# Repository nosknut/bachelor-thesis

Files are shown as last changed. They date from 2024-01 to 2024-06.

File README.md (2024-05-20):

# Bachelor Thesis

This repository was developed as part of an Electronic Engineering Bachelor Thesis. The [report](report.pdf) serves as a design and maintainance document and contains useful information and diagrams explaining the different software mechanisms.

## Setup

### Windows (WSL)

- [WSL Setup](docs/setup/wsl/wsl/README.md)
- [Docker Setup](docs/setup/wsl/docker/README.md)

### Ubuntu

- [ROS2 Setup](https://docs.ros.org/en/humble/Installation/Ubuntu-Install-Debians.html)

### Common

After cloning the repository, run the following command to ignore changes to the workspace configs:

```bash
bash scripts/git/ignore_local_config_file_changes.bash
```

## Docs

- [Config Explanations](docs/config-explanations/README.md)
- [Docker Commands](docs/docker-commands/README.md)

## Project overview

The project contains 6 ROS2 packages:

- twig
  - The main entry point of the robot. The other packages in the project should not be used directly, but rather be included in launchfiles from this package.
- twig_description
  - Contains the URDF for the robot
- twig_servo
  - Contains the moveit_servo note that allows jogging individual joints through moveit's planning interface.
- twig_teleop
  - Contains two separate nodes that turn joy messages into useful commands for other nodes.
- twig_moveit_config
  - A moveit config package generated by the [Moveit Setup Assistant](https://moveit.picknik.ai/main/doc/examples/setup_assistant/setup_assistant_tutorial.html). It handles kinematics, path planning, collision avoidance and has an action server for requesting target positions.
- twig_hardware
  - Contains the ros2_control hardware interfaces for the robot, as well as a diagnostics node for debugging that does not use ros2_control.

## Cleaning the workspace

```bash
bash scripts/ros2/purge.bash
```

## Installing dependencies

```bash
bash scripts/ros2/install-dependencies.bash
```

## Building

```bash
bash scripts/ros2/build-packages.bash
```

## Launching

The project contains 3 different launch configurations.
- Normal Operation
  - Requires hardware
  - Based on ros2_control and MoveIt
  - Contains
    - collision, endpoint and singularity avoidance
    - Transform publishers
    - PID controllers
- Diagnostics
  - Requires hardware
  - Contains
    - A single simple hardware node that publishes all sensor data and forwards all commands directly to servos.
    - A teleop node to transform joy messages into servo speed and relay state commands
- ROS2 Development
  - Does not require hardware
  - Identical to Normal Operation
  - Replaces the hardware interfaces with Mocked Components from ros2_control

### Normal Operation

On the robot

```bash
ros2 launch twig robot_moveit.launch.py
ros2 launch twig servo_teleop.launch.py
```

On the GUI pc

```bash
ros2 launch twig joy.launch.py
ros2 launch twig foxglove.launch.py
```

and optionally on the GUI pc

```bash
ros2 launch twig rviz.launch.py
```

### Diagnostics

On the robot

```bash
ros2 launch twig diagnostics.launch.py
```

On the GUI pc

```bash
ros2 launch twig joy.launch.py
ros2 launch twig foxglove.launch.py
```

## ROS2 Development

```bash
ros2 launch twig moveit_demo.launch.py
```

Publish to /twig_joy using the foxglove Joystick node.

## Development

For development, [open the repository in the ROS2 devcontainer](https://code.visualstudio.com/docs/devcontainers/containers), and use the ROS2 task buttons in the status bar to install dependencies and build the project. While in the devcontainer, use the ROS2 Development configuration to run the project and visualize the robots physical state in RVIz. For more detailed information surrounding the development environment, refer to the [original template](https://github.com/athackst/vscode_ros2_workspace) by athackst.

In [Command Palette](https://code.visualstudio.com/docs/getstarted/userinterface#_command-palette):
```
Dev Containers: Reopen in Container
Tasks: Run Task
  ROS2: Install Dependencies
  ROS2: Build Packages
  ROS2: Run Package
```

## Citations

When citing software, docs and configuration:

```bibtex
@online{
    author = "Knut Ola Nøsen",
    title = "Subsea 3DOF Robotic Manipulator",
    url = "https://github.com/nosknut/bachelor-thesis/tree/submitted-with-report",
    urldate = "2024-05-20"
}
```

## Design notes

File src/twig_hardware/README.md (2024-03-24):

https://github.com/vortexntnu/vortex-asv/tree/master/motion/thruster_interface

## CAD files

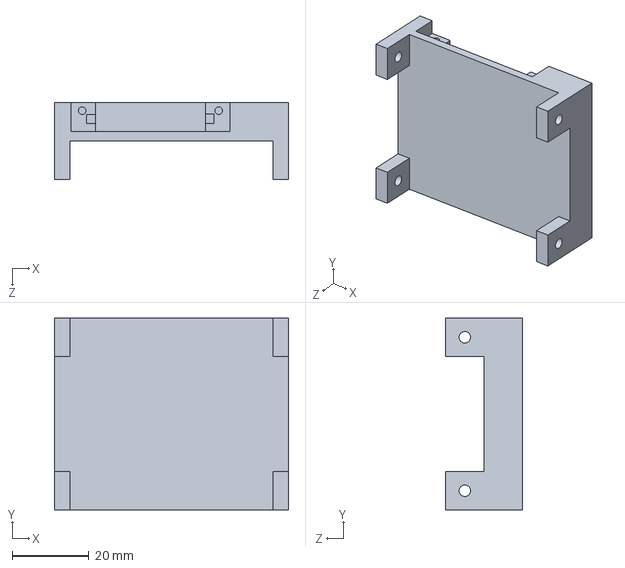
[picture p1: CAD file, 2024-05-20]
src/twig_3d_models/twig/twig_main_housing_encoder_gripper_mount_2.SLDPRT
61.0 x 50.0 x 20.0 mm

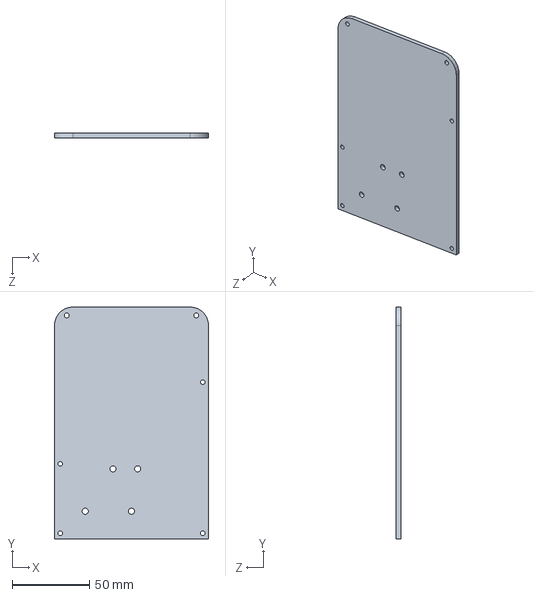
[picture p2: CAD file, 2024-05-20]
src/twig_3d_models/twig/twig_main_housing_top_lid.SLDPRT
100.0 x 150.5 x 3.00 mm

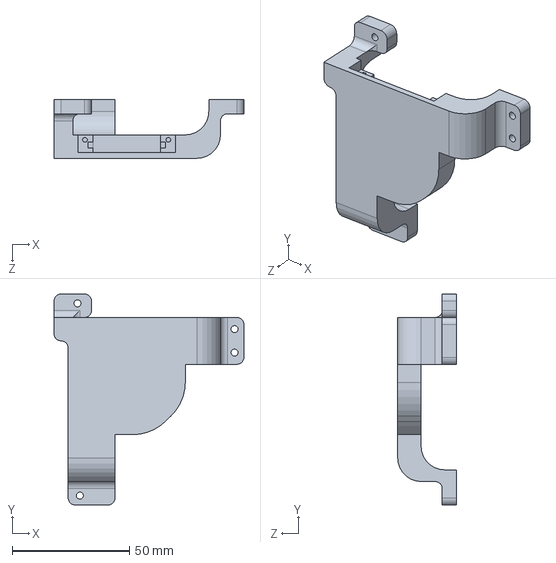
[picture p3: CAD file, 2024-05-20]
src/twig_3d_models/twig/twig_main_housing_encoder_wrist_mount_2.SLDPRT
81.0 x 90.0 x 25.0 mm

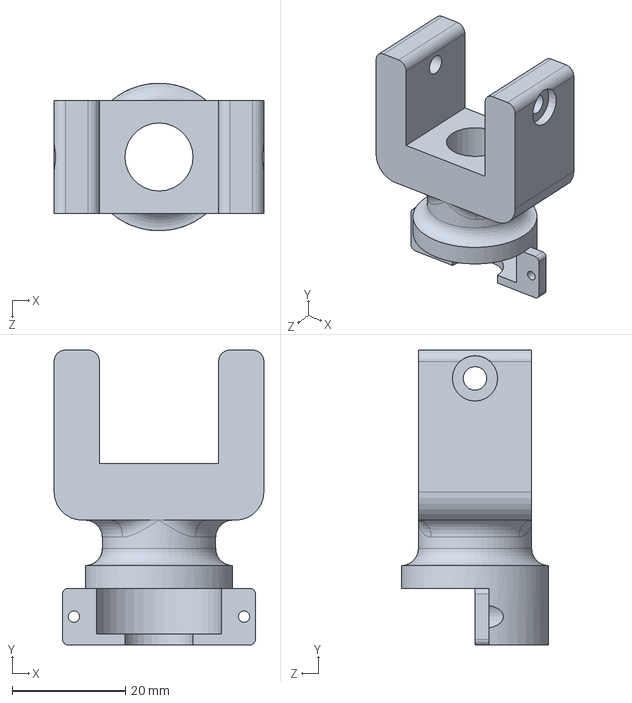
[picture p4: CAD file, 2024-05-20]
src/twig_3d_models/twig/twig_arm_clamping_movable adapter.SLDPRT
37.0 x 52.0 x 26.0 mm

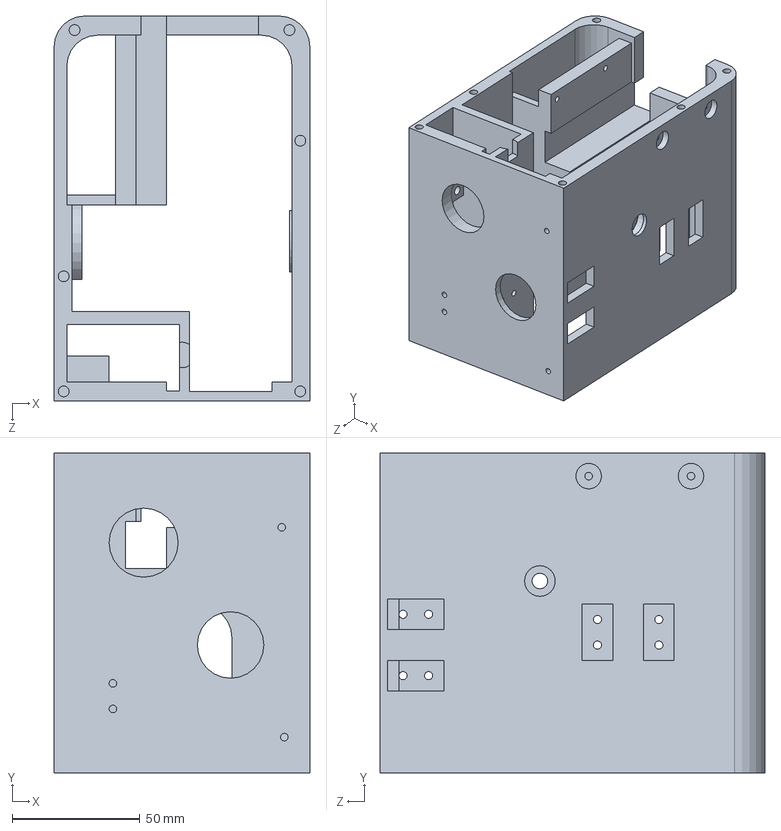
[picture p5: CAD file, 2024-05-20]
src/twig_3d_models/twig/twig_housing.SLDPRT
100.0 x 125.0 x 150.5 mm

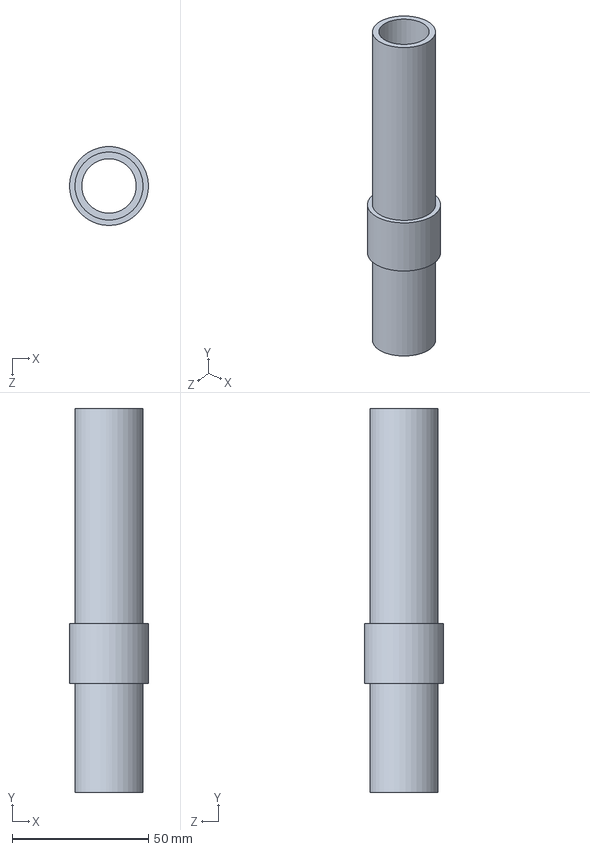
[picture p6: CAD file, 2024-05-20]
src/twig_3d_models/twig/twig_arm_innerstructure-LAPTOP-5HQE7ROM.SLDPRT
29.0 x 141.0 x 29.0 mm

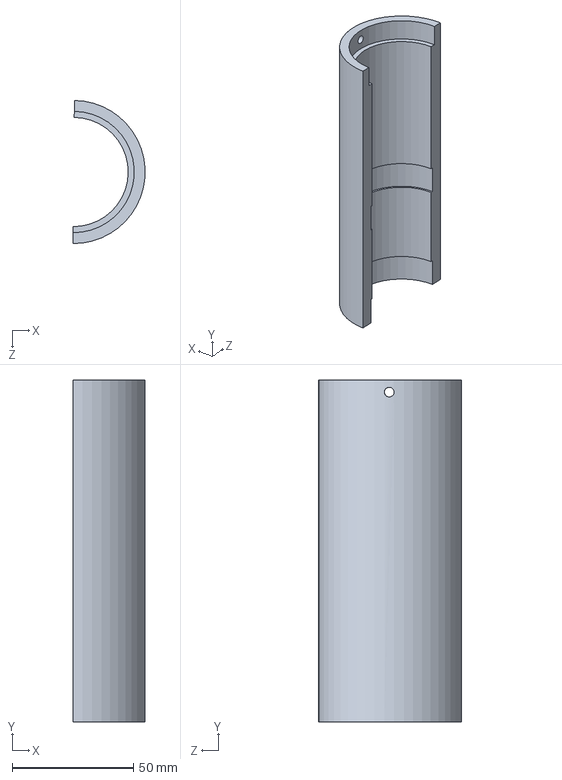
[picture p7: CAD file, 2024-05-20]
src/twig_3d_models/twig/twig_arm_outer_shell_lid-LAPTOP-5HQE7ROM.SLDPRT
29.8 x 141.0 x 59.0 mm

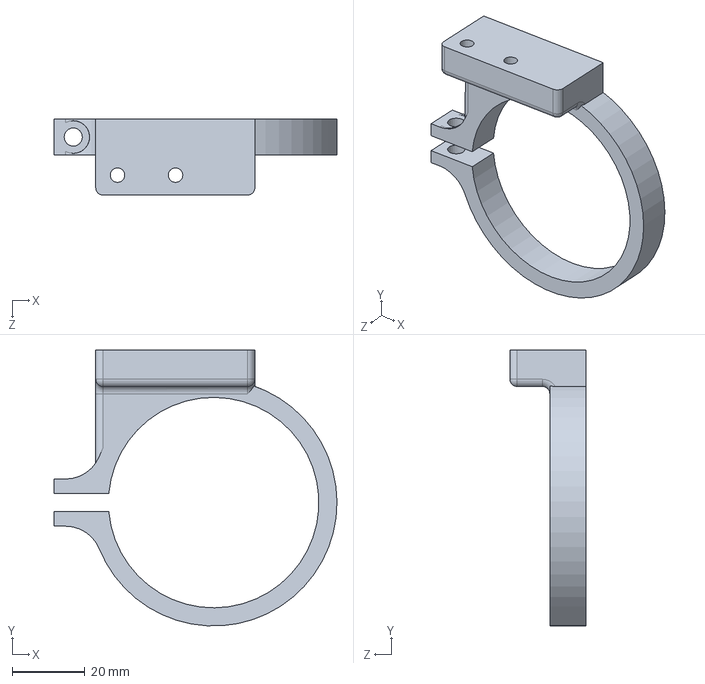
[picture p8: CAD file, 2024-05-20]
src/twig_3d_models/twig/twig_camera_adapter_2.SLDPRT
78.0 x 75.9 x 21.0 mm

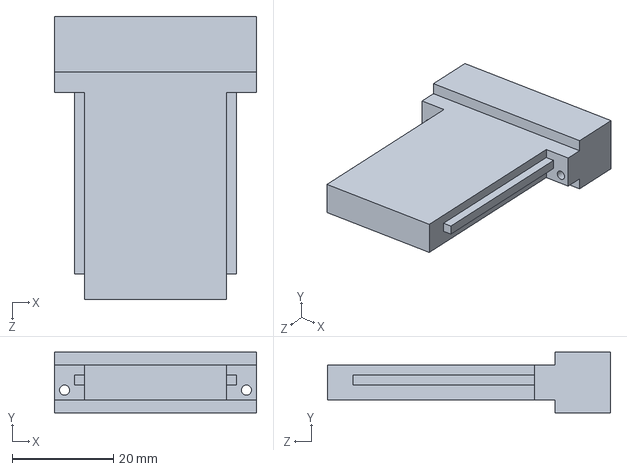
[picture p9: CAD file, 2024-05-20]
src/twig_3d_models/twig/twig_encoder_cartridge.SLDPRT
40.0 x 12.0 x 56.0 mm

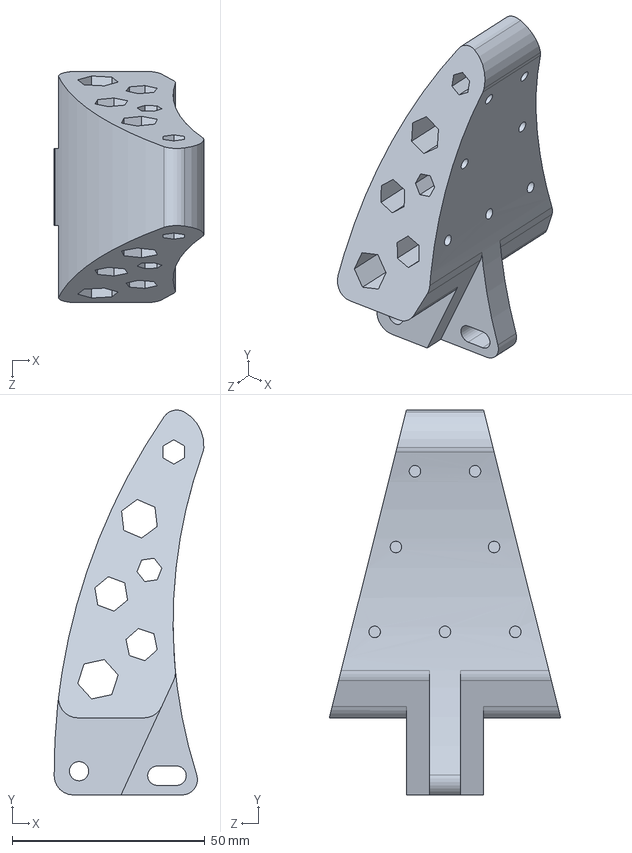
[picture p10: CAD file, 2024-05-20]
src/twig_3d_models/twig/twig_arm_clamping_claw_part_2.SLDPRT
38.8 x 99.8 x 60.0 mm

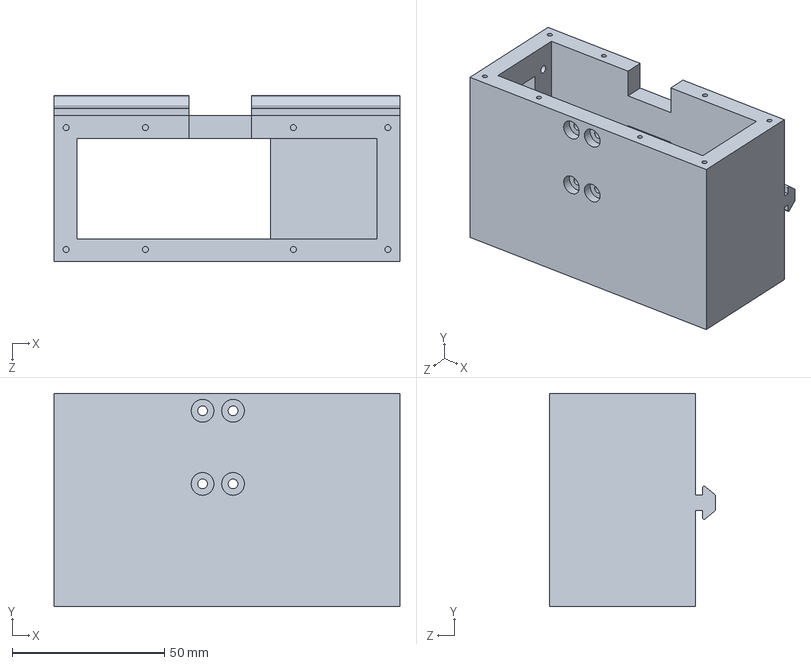
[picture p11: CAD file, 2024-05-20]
src/twig_3d_models/twig/twig_side_mounts_right_servo_housing.SLDPRT
113.6 x 70.0 x 54.6 mm

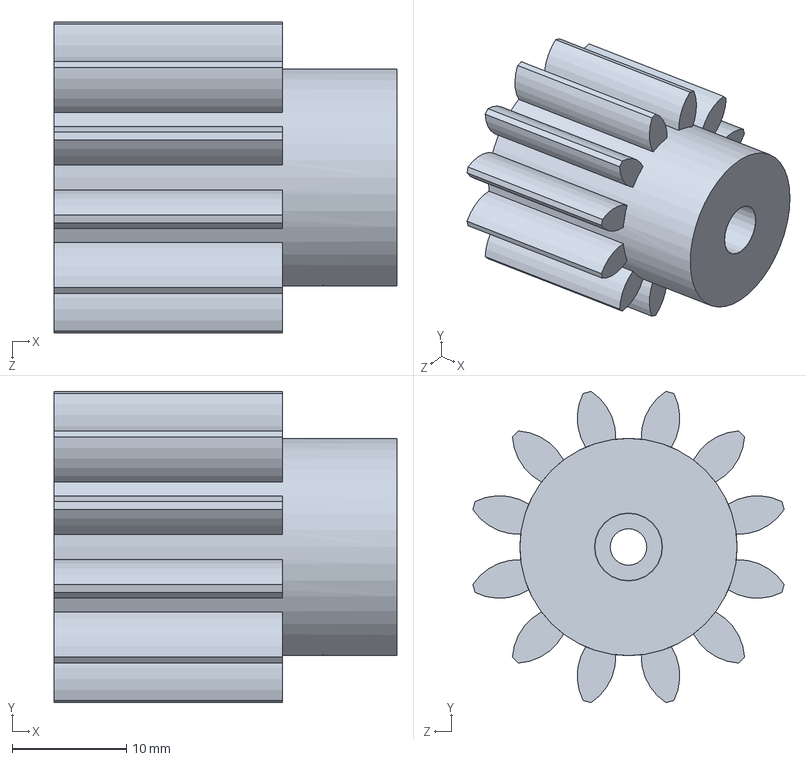
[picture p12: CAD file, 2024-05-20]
src/twig_3d_models/twig/twig_housing_gripper_pinion.SLDPRT
30.0 x 27.2 x 27.2 mm

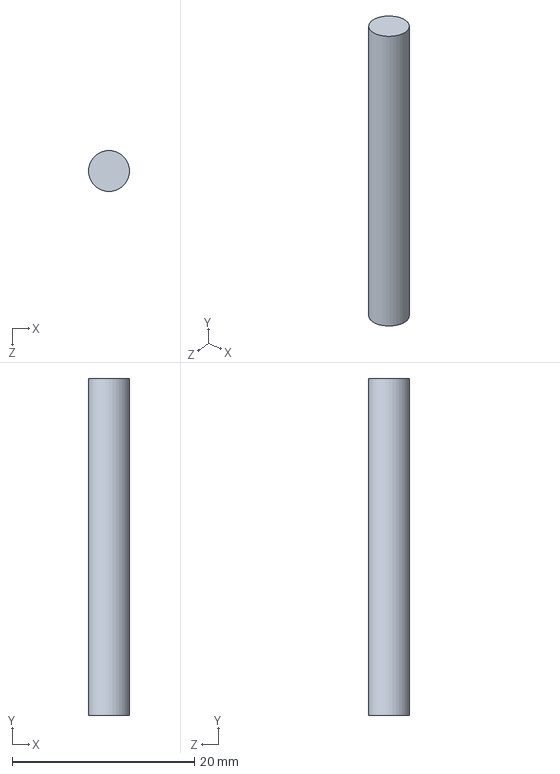
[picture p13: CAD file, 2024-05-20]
src/twig_3d_models/twig/twig_arm_clamping_pin4_movable_adapter.SLDPRT
4.50 x 37.0 x 4.50 mm

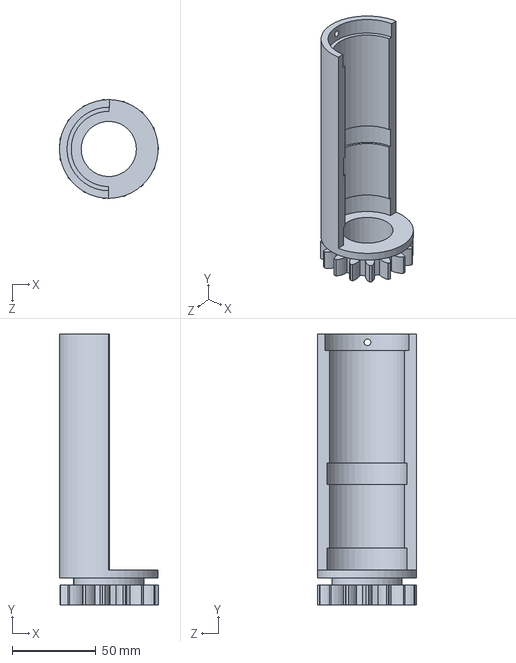
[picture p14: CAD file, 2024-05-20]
src/twig_3d_models/twig/twig_arm_outer_shell_gear.SLDPRT
59.2 x 162.0 x 59.3 mm

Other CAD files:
src/twig_3d_models/twig/twig_housing_assembly.SLDASM
src/twig_3d_models/twig/twig_arm_assembly.SLDASM
src/twig_3d_models/twig/twig_housing_gripper_rack_gear.SLDPRT
src/twig_3d_models/twig/twig_arm_innerstructure.SLDPRT
src/twig_3d_models/twig/twig_arm_47mm_bearing.SLDPRT
src/twig_3d_models/twig/twig_arm_center_shaft.SLDPRT
src/twig_3d_models/twig/twig_arm_clamping_adapter_claw.SLDPRT
src/twig_3d_models/twig/twig_arm_clamping_claw part_1.SLDPRT
src/twig_3d_models/twig/twig_arm_clamping_m6_rod.SLDPRT
src/twig_3d_models/twig/twig_arm_clamping_movable adapter_part2.SLDPRT
src/twig_3d_models/twig/twig_arm_clamping_rotating_pins.SLDPRT
src/twig_3d_models/twig/twig_arm_innerlockring.SLDPRT
src/twig_3d_models/twig/twig_arm_outer_shell_gear-LAPTOP-5HQE7ROM.SLDPRT
src/twig_3d_models/twig/twig_arm_outer_shell_lid.SLDPRT
src/twig_3d_models/twig/twig_camera_adapter_1.SLDPRT
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

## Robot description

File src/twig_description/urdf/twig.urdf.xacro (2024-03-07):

<?xml version="1.0"?>

<robot xmlns:xacro="http://www.ros.org/wiki/xacro" name="twig">

  <xacro:property name="name" value="twig" />

  <xacro:property name="base_length" value="0.08" />
  <xacro:property name="base_radius" value="0.12" />
  <xacro:property name="base_width" value="0.1" />

  <xacro:property name="shoulder_length" value="0.2" />
  <xacro:property name="shoulder_radius" value="0.05" />
  
  <xacro:property name="wrist_length" value="0.01" />
  <xacro:property name="wrist_radius" value="0.05" />

  <xacro:property name="gripper_length" value="0.05" />
  <xacro:property name="gripper_width" value="0.05" />
  <xacro:property name="gripper_height" value="0.1" />

  <xacro:property name="shoulder_limit" value="${(pi/180)*100}" />
  <xacro:property name="wrist_limit" value="${(pi/180)*360}" />
  <xacro:property name="gripper_limit" value="${(pi/180)*20}" />

  <xacro:property name="shoulder_velocity_limit" value="5.0" />
  <xacro:property name="wrist_velocity_limit" value="5.0" />
  <xacro:property name="gripper_velocity_limit" value="1.0" />

  <xacro:property name="shoulder_effort_limit" value="5.0" />
  <xacro:property name="wrist_effort_limit" value="5.0" />
  <xacro:property name="gripper_effort_limit" value="0.1" />


  <material name="blue">
    <color rgba="0 0 1 1" />
  </material>

  <material name="red">
    <color rgba="1 0 0 1" />
  </material>

  <material name="black">
    <color rgba="0 0 0 1" />
  </material>

  <material name="white">
    <color rgba="1 1 1 1" />
  </material>

  <material name="grey">
    <color rgba="0.5 0.5 0.5 1" />
  </material>

  <link name="base_link">
    <visual>
      <geometry>
        <cylinder length="1" radius="0.15" />
      </geometry>
      <material name="grey" />
      <origin rpy="0 ${pi/2} 0" />
    </visual>
    <collision>
      <geometry>
        <cylinder length="1" radius="0.15" />
      </geometry>
      <origin rpy="0 ${pi/2} 0" />
    </collision>
  </link>

  <link name="${name}_base">
    <visual>
      <geometry>
        <cylinder length="${base_width}" radius="${base_radius}" />
      </geometry>
      <material name="grey" />
      <origin rpy="0 ${pi/2} ${pi/2}" />
    </visual>
    <collision>
      <geometry>
        <cylinder length="${base_width}" radius="${base_radius}" />
      </geometry>
      <origin rpy="0 ${pi/2} ${pi/2}" />
    </collision>
  </link>

  <link name="${name}_shoulder">
    <visual>
      <geometry>
        <cylinder length="${shoulder_length}" radius="${shoulder_radius}" />
      </geometry>
      <origin xyz="0 0 ${shoulder_length/2}" />
      <material name="red" />
    </visual>
    <collision>
      <geometry>
        <cylinder length="${shoulder_length}" radius="${shoulder_radius}" />
      </geometry>
      <origin xyz="0 0 ${shoulder_length/2}" />
    </collision>
  </link>

  <link name="${name}_wrist">
    <visual>
      <geometry>
        <cylinder length="${wrist_length}" radius="${wrist_radius}" />
      </geometry>
      <origin xyz="0 0 ${wrist_length/2}" />
      <material name="white" />
    </visual>
    <collision>
      <geometry>
        <cylinder length="${wrist_length}" radius="${wrist_radius}" />
      </geometry>
      <origin xyz="0 0 ${wrist_length/2}" />
    </collision>
  </link>

  <link name="${name}_gripper">
  </link>

  <link name="${name}_left_gripper">
    <visual>
      <geometry>
        <box size="${gripper_length} ${gripper_width} ${gripper_height}" />
      </geometry>
      <origin xyz="${-gripper_length/2} 0 ${gripper_height/2}" />
      <material name="blue" />
    </visual>
    <collision>
      <geometry>
        <box size="${gripper_length} ${gripper_width} ${gripper_height}" />
      </geometry>
      <origin xyz="${-gripper_length/2} 0 ${gripper_height/2}" />
    </collision>
  </link>

  <link name="${name}_right_gripper">
    <visual>
      <geometry>
        <box size="${gripper_length} ${gripper_width} ${gripper_height}" />
      </geometry>
      <origin xyz="${gripper_length/2} 0 ${gripper_height/2}" />
      <material name="blue" />
    </visual>
    <collision>
      <geometry>
        <box size="${gripper_length} ${gripper_width} ${gripper_height}" />
      </geometry>
      <origin xyz="${gripper_length/2} 0 ${gripper_height/2}" />
    </collision>
  </link>

  <joint name="${name}_base_joint" type="fixed">
    <parent link="base_link" />
    <child link="${name}_base" />
    <origin xyz="0.5 0 0" rpy="0 ${pi/2} 0" />
  </joint>

  <joint name="${name}_shoulder_joint" type="revolute">
    <parent link="${name}_base" />
    <child link="${name}_shoulder" />
    <axis rpy="0 0 0" xyz="0 -1 0" />
    <origin xyz="0 0 ${base_length}" />
    <limit effort="${shoulder_effort_limit}" lower="${-shoulder_limit}" upper="${shoulder_limit}" velocity="${shoulder_velocity_limit}"/>
  </joint>

  <joint name="${name}_wrist_joint" type="revolute">
    <parent link="${name}_shoulder" />
    <child link="${name}_wrist" />
    <axis rpy="0 0 0" xyz="0 0 -1" />
    <origin xyz="0 0 ${shoulder_length}" />
    <limit effort="${wrist_effort_limit}" lower="${-wrist_limit}" upper="${wrist_limit}" velocity="${wrist_velocity_limit}"/>
  </joint>

  <joint name="${name}_gripper_joint" type="fixed">
    <parent link="${name}_wrist" />
    <child link="${name}_gripper" />
    <origin xyz="0 0 ${gripper_height}" />
  </joint>

  <joint name="${name}_left_finger_joint" type="revolute">
    <parent link="${name}_wrist" />
    <child link="${name}_left_gripper" />
    <axis rpy="0 0 0" xyz="0 -1 0" />
    <limit effort="${gripper_effort_limit}" lower="0" upper="${gripper_limit}" velocity="${gripper_velocity_limit}"/>
  </joint>

  <joint name="${name}_right_finger_joint" type="revolute">
    <parent link="${name}_wrist" />
    <child link="${name}_right_gripper" />
    <axis rpy="0 0 0" xyz="0 1 0" />
    <limit effort="${gripper_effort_limit}" lower="0" upper="${gripper_limit}" velocity="${gripper_velocity_limit}"/>
    <mimic joint="twig_left_finger_joint" />
  </joint>
</robot>

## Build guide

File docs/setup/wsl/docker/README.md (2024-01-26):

[<-- Back](/README.md)

# Docker

Docker is a service that allows you to run applications in containers without installing the programs on your actual machine. This allows for a standardized environment for running applications, and makes it easier to share code with others. It also takes a lot of debugging off your hands when working across different computers and team members.

## Install Docker

Follow the instructions on [this](https://docs.docker.com/desktop/install/windows-install/) website to install docker.

## Configure Docker in WSL

Follow the instructions on [this](https://docs.docker.com/desktop/wsl/) website to make docker commands available in the WSL terminal.

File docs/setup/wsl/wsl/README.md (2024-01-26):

[<-- Back](/README.md)

# WSL

The following instructions are for installing and using windows subsystem for linux (WSL), which allows you to run docker desktop and linux GUI applications directly in windows.

## Install WSL

- Follow the instructions in [this](https://youtu.be/AMlaEFaKG88?si=Uk1TH-ulXn2jgdA9) video or [this](https://docs.microsoft.com/en-us/windows/wsl/install-win10) website to install WSL.
- Make sure WSL2 is the default version
```bash
wsl --set-default-version 2
```
- [Install Ubuntu WSL](https://apps.microsoft.com/detail/9PDXGNCFSCZV?hl=en-us&gl=US) from the Microsoft Store.
- Run the setup by launching the Ubuntu app from the start menu
- [Configure WSL GUI Support](https://learn.microsoft.com/en-us/windows/wsl/tutorials/gui-apps) by running the following commands in powershell
```bash
wsl --update
```

## Launch wsl terminal from VSCode

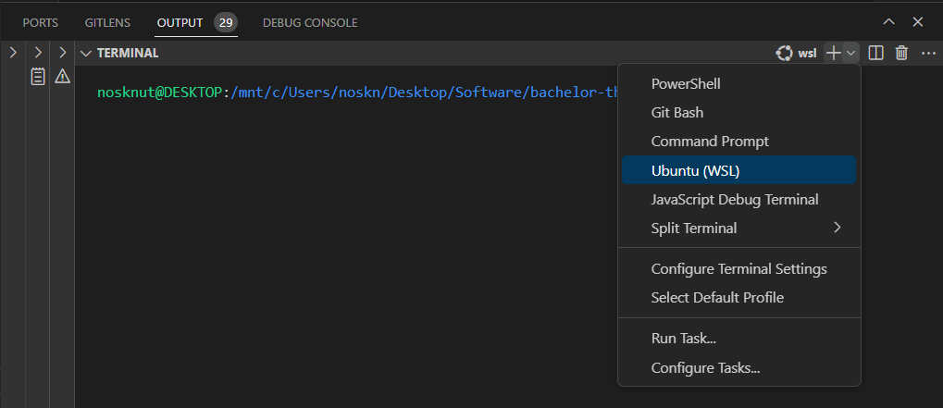
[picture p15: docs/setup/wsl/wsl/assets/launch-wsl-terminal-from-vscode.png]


## Create symlink to project in WSL home directory

It is practical to create a shortcut the project folder in the WSL home directory. This way, you can easily access the project folder from any GUI application running in WSL.

```bash
ln -s /mnt/c/Users/username/path/to/<project-name> ~/<project-name>
```

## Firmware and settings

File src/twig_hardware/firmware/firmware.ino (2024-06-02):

// How to flash the firmware to Raspberry Pi Pico from Arduino IDE:
// https://randomnerdtutorials.com/programming-raspberry-pi-pico-w-arduino-ide/#Raspberry-Pi-Pico-Boards-Manager
// Additional URL:
// https://github.com/earlephilhower/arduino-pico/releases/download/global/package_rp2040_index.json
// Board manager:
// Raspberry Pi Pico/RP2040 by Earle F. Philhower, III Version 3.8.0 INSTALLED
// Serial port not showing up:
// https://forum.arduino.cc/t/raspberry-pi-pico-does-not-show-its-port-in-ide/850432/10

#include "FirmwareConfig.h"

#include <Wire.h>
#include <Servo.h>
#include "hardware/watchdog.h"
#include "TwigState.h"
#include "TwigCommand.h"
#include "TwigHardwareConfig.h"
#include "FusedServo.h"
#include "I2cMultiplexer.h"

// #define DEBUG_ENCODERS
#include "Encoder.h"

I2cMultiplexer i2cMultiplexer = I2cMultiplexer(Wire1, MULTIPLEXER_ADDRESS);
Encoder shoulderEncoder = Encoder(i2cMultiplexer, SHOULDER_ENCODER_CHANNEL, INITIAL_MIN_ENCODER_MAGNITUDE, "Shoulder");
Encoder wristEncoder = Encoder(i2cMultiplexer, WRIST_ENCODER_CHANNEL, INITIAL_MIN_ENCODER_MAGNITUDE, "Wrist");
Encoder gripperEncoder = Encoder(i2cMultiplexer, GRIPPER_ENCODER_CHANNEL, INITIAL_MIN_ENCODER_MAGNITUDE, "Gripper");

FusedServo shoulderServo(SHOULDER_SERVO_PIN, SHOULDER_SERVO_RELAY_PIN);
FusedServo wristServo(WRIST_SERVO_PIN, WRIST_SERVO_RELAY_PIN);
FusedServo gripperServo(GRIPPER_SERVO_PIN, GRIPPER_SERVO_RELAY_PIN);

TwigCommand twigCommand;
TwigState twigState;

unsigned long connectionTimeout = INITIAL_CONNECTION_TIMEOUT;
unsigned long connectionTimer = 0;
unsigned long logTimer = 0;

unsigned long sent = 0;
unsigned long received = 0;

void resetCommand()
{
  twigCommand.sessionId = twigState.sessionId;
  twigCommand.shoulder = 0;
  twigCommand.wrist = 0;
  twigCommand.gripper = 0;
  twigCommand.shoulderServoPowered = false;
  twigCommand.wristServoPowered = false;
  twigCommand.gripperServoPowered = false;
}

bool verify_session_id()
{
  return twigCommand.sessionId == twigState.sessionId;
}

void updateHardwareConfig() {
  TwigHardwareConfig &config = twigCommand.config;

  connectionTimeout = config.connectionTimeout;

  shoulderEncoder.minMagnitude = config.encoderMinMagnitude;
  wristEncoder.minMagnitude = config.encoderMinMagnitude;
  gripperEncoder.minMagnitude = config.encoderMinMagnitude;

  shoulderServo.fuse.maxCurrent = config.maxShoulderCurrent;
  wristServo.fuse.maxCurrent = config.maxWristCurrent;
  gripperServo.fuse.maxCurrent = config.maxGripperCurrent;

  shoulderServo.fuse.maxCurrentDuration = config.maxCurrentDuration;
  wristServo.fuse.maxCurrentDuration = config.maxCurrentDuration;
  gripperServo.fuse.maxCurrentDuration = config.maxCurrentDuration;

  shoulderServo.fuse.maxCurrentCooldownDuration = config.maxCurrentCooldownDuration;
  wristServo.fuse.maxCurrentCooldownDuration = config.maxCurrentCooldownDuration;
  gripperServo.fuse.maxCurrentCooldownDuration = config.maxCurrentCooldownDuration;
}

void writeCommand()
{
  if (!verify_session_id()) return;
  shoulderServo.update(twigState.shoulderCurrent, twigCommand.shoulderServoPowered, twigCommand.shoulder);
  wristServo.update(twigState.wristCurrent, twigCommand.wristServoPowered, twigCommand.wrist);
  gripperServo.update(twigState.gripperCurrent, twigCommand.gripperServoPowered, twigCommand.gripper);
}

void onCommand(int length)
{
  TwigCommand payload;
  Wire.readBytes((uint8_t *)&payload, length);
  if (payload.integrityCheck != 85) {
    Serial.println("Command integrity check failed");
    return;
  }
  twigCommand = payload;
  updateHardwareConfig();
  if (verify_session_id()) connectionTimer = millis();
  received++;
}

void readState()
{
  twigState.wristCurrent = analogRead(WRIST_CURRENT_PIN);
  twigState.gripperCurrent = analogRead(GRIPPER_CURRENT_PIN);
  twigState.shoulderCurrent = analogRead(SHOULDER_CURRENT_PIN);

  twigState.wristPosition = wristEncoder.values.angle;
  twigState.wristVelocity = wristEncoder.values.velocity;
  twigState.wristEncoderMagnitude = wristEncoder.values.magnitude;

  twigState.shoulderPosition = shoulderEncoder.values.angle;
  twigState.shoulderVelocity = shoulderEncoder.values.velocity;
  twigState.shoulderEncoderMagnitude = shoulderEncoder.values.magnitude;

  twigState.gripperPosition = gripperEncoder.values.angle;
  twigState.gripperVelocity = gripperEncoder.values.velocity;
  twigState.gripperEncoderMagnitude = gripperEncoder.values.magnitude;

  twigState.wristServoPowered = wristServo.relayState;
  twigState.shoulderServoPowered = shoulderServo.relayState;
  twigState.gripperServoPowered = gripperServo.relayState;
}

void onStateRequest()
{
  Wire.write((uint8_t *)&twigState, sizeof(TwigState));
  if (verify_session_id()) connectionTimer = millis();
  sent++;
}

void setupOutputs()
{
  shoulderServo.begin();
  wristServo.begin();
  gripperServo.begin();
}

String leadingSpaces(String val, int length)
{
  int valLen = val.length();
  String out = "";
  for (int i = 0; i < length - valLen; i++)
  {
    out += " ";
  }
  out += val;
  return out;
}

void printLog()
{
  Serial.print("Sending at: ");
  Serial.print(sent * 10);
  Serial.print("Hz, Receiving at: ");
  Serial.print(received * 10);
  Serial.print("Hz, ");
  Serial.print(leadingSpaces(String(twigCommand.shoulder), 7));
  Serial.print(", ");
  Serial.print(leadingSpaces(String(twigCommand.wrist), 7));
  Serial.print(", ");
  Serial.print(leadingSpaces(String(twigCommand.gripper), 7));
  Serial.print(", ");
  Serial.print(leadingSpaces(String(twigState.shoulderEncoderMagnitude), 7));
  Serial.print(", ");
  Serial.print(leadingSpaces(String(twigState.wristEncoderMagnitude), 7));
  Serial.print(", ");
  Serial.print(leadingSpaces(String(twigState.gripperEncoderMagnitude), 7));
  Serial.print(", ");
  Serial.print(twigCommand.shoulderServoPowered);
  Serial.print(", ");
  Serial.print(twigCommand.wristServoPowered);
  Serial.print(", ");
  Serial.println(twigCommand.gripperServoPowered);
}

void updateLog()
{
  if ((millis() - logTimer) >= 100)
  {
    printLog();
    sent = 0;
    received = 0;
    logTimer = millis();
  }
}

void updateConnectionTimer()
{
  if ((millis() - connectionTimer) > connectionTimeout)
  {
    resetCommand();
    Serial.println("Connection timeout");
  }
}

void setup()
{
  // Used to detect that the microcontroller rebooted
  randomSeed(analogRead(SESSION_ID_RANDOM_SEED_PIN));
  twigState.sessionId = random(1, 10000);

  setupOutputs();
  resetCommand();

  Serial.begin(SERIAL_BAUD_RATE);

  Serial.println("Starting ...");

  // https://github.com/raspberrypi/pico-examples/blob/master/watchdog/hello_watchdog/hello_watchdog.c
  // Enable the watchdog, requiring the watchdog to be updated every 100ms or the chip will reboot
  // second arg is pause on debug which means the watchdog will pause when stepping through code
  watchdog_enable(1000, 1);

  Wire.setSCL(RASPBERRY_PI_SCL_PIN);
  Wire.setSDA(RASPBERRY_PI_SDA_PIN);
  
  Wire.begin(I2C_ADDRESS);
  Wire.onReceive(onCommand);
  Wire.onRequest(onStateRequest);

}

void loop()
{
    readState();
    updateLog();
    updateConnectionTimer();
    writeCommand();
    watchdog_update();
}

// The encoders might crash if they get destroyed, which can freeze the firmware.
// To allow normal operations without the encoders, they are exclusively read and updated
// in a separate core.
void setup1()
{
  Wire1.setSCL(MULTIPLEXER_SCL_PIN);
  Wire1.setSDA(MULTIPLEXER_SDA_PIN);
  Wire1.setClock(MULTIPLEXER_FREQUENCY);
  Wire1.setTimeout(MULTIPLEXER_TIMEOUT);
  Wire1.begin();
}

// The encoders might crash if they get destroyed, which can freeze the firmware.
// To allow normal operations without the encoders, they are exclusively read and updated
// in a separate core.
void loop1()
{
  wristEncoder.update();
  shoulderEncoder.update();
  // TODO: Fix the gripper encoder and re-enable it in firmware
  // gripperEncoder.update();
}

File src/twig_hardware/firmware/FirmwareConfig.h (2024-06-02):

#ifndef FIRMWARE_CONFIG_h
#define FIRMWARE_CONFIG_h

const int8_t I2C_ADDRESS = 30;
const unsigned long SERIAL_BAUD_RATE = 115200;

const int SERVO_STATIONARY_SIGNAL = 1500;

const int INITIAL_MIN_ENCODER_MAGNITUDE = 10;

const int POSITION_LOWPASS_FILTER_ORDER = 2;
const float POSITION_LOWPASS_FILTER_CUTOFF = 2.0;

// To protect the system in the event of a connection loss,
// the system will stop moving if it does not detect activity
// within the specified number of milliseconds.
const unsigned long INITIAL_CONNECTION_TIMEOUT = 200;

const int8_t RASPBERRY_PI_SDA_PIN = 20;
const int8_t RASPBERRY_PI_SCL_PIN = 21;

// https://www.elfadistrelec.no/no/i2c-multiplexer-adafruit-2717/p/30091194
const uint32_t MULTIPLEXER_FREQUENCY = 100e3;
const uint32_t MULTIPLEXER_TIMEOUT = 500;
const int8_t MULTIPLEXER_ADDRESS = 0x70;
const int8_t MULTIPLEXER_SCL_PIN = 19;
const int8_t MULTIPLEXER_SDA_PIN = 18;

const int8_t SHOULDER_ENCODER_CHANNEL = 3;
const int8_t WRIST_ENCODER_CHANNEL = 2;
const int8_t GRIPPER_ENCODER_CHANNEL = 4;

const int8_t SHOULDER_CURRENT_PIN = A0;
const int8_t WRIST_CURRENT_PIN = A1;
const int8_t GRIPPER_CURRENT_PIN = A2;

const int8_t SESSION_ID_RANDOM_SEED_PIN = A2;

const int8_t SHOULDER_SERVO_PIN = 3;
const int8_t WRIST_SERVO_PIN = 12;
const int8_t GRIPPER_SERVO_PIN = 8;

const int8_t SHOULDER_SERVO_RELAY_PIN = 9;
const int8_t WRIST_SERVO_RELAY_PIN = 11;
const int8_t GRIPPER_SERVO_RELAY_PIN = 10;

#endif

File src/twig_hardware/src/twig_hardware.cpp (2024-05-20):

// https://github.com/ros-controls/ros2_control_demos/blob/humble/example_12/hardware/rrbot.cpp

// Copyright 2023 ros2_control Development Team
//
// Licensed under the Apache License, Version 2.0 (the "License");
// you may not use this file except in compliance with the License.
// You may obtain a copy of the License at
//
//     http://www.apache.org/licenses/LICENSE-2.0
//
// Unless required by applicable law or agreed to in writing, software
// distributed under the License is distributed on an "AS IS" BASIS,
// WITHOUT WARRANTIES OR CONDITIONS OF ANY KIND, either express or implied.
// See the License for the specific language governing permissions and
// limitations under the License.

#include "twig_hardware/twig_hardware.hpp"

#include <chrono>
#include <cmath>
#include <limits>
#include <memory>
#include <vector>

#include "hardware_interface/types/hardware_interface_type_values.hpp"
#include "rclcpp/rclcpp.hpp"

namespace twig_hardware
{
hardware_interface::CallbackReturn TwigHardware::on_init(
  const hardware_interface::HardwareInfo & info)
{
  if (
    hardware_interface::SystemInterface::on_init(info) !=
    hardware_interface::CallbackReturn::SUCCESS)
  {
    return hardware_interface::CallbackReturn::ERROR;
  }

  hw_commands_.resize(info_.joints.size() * 1, std::numeric_limits<double>::quiet_NaN());
  hw_states_.resize(info_.joints.size() * 3, std::numeric_limits<double>::quiet_NaN());

  for (const hardware_interface::ComponentInfo & joint : info_.joints) {
    // TwigHardware has exactly 1 command and 3 state interfaces on each joint

    // Validate command interface configs

    if (joint.command_interfaces.size() != 1) {
      RCLCPP_FATAL(
        rclcpp::get_logger("TwigHardware"),
        "Joint '%s' has %zu command interfaces found. 1 expected.", joint.name.c_str(),
        joint.command_interfaces.size());
      return hardware_interface::CallbackReturn::ERROR;
    }

    // Validate command interface 1 config

    if (joint.command_interfaces[0].name != hardware_interface::HW_IF_VELOCITY) {
      RCLCPP_FATAL(
        rclcpp::get_logger("TwigHardware"),
        "Joint '%s' have %s command interfaces found. '%s' expected.", joint.name.c_str(),
        joint.command_interfaces[0].name.c_str(), hardware_interface::HW_IF_VELOCITY);
      return hardware_interface::CallbackReturn::ERROR;
    }

    // Validate state interface configs

    if (joint.state_interfaces.size() != 3) {
      RCLCPP_FATAL(
        rclcpp::get_logger("TwigHardware"),
        "Joint '%s' has %zu state interface. 3 expected.", joint.name.c_str(),
        joint.state_interfaces.size());
      return hardware_interface::CallbackReturn::ERROR;
    }

    // Validate state interface 1 config

    if (joint.state_interfaces[0].name != hardware_interface::HW_IF_POSITION) {
      RCLCPP_FATAL(
        rclcpp::get_logger("TwigHardware"),
        "Joint '%s' have %s state interface. '%s' expected.", joint.name.c_str(),
        joint.state_interfaces[0].name.c_str(), hardware_interface::HW_IF_POSITION);
      return hardware_interface::CallbackReturn::ERROR;
    }

    // Validate state interface 2 config

    if (joint.state_interfaces[1].name != hardware_interface::HW_IF_VELOCITY) {
      RCLCPP_FATAL(
        rclcpp::get_logger("TwigHardware"),
        "Joint '%s' have %s state interface. '%s' expected.", joint.name.c_str(),
        joint.state_interfaces[1].name.c_str(), hardware_interface::HW_IF_VELOCITY);
      return hardware_interface::CallbackReturn::ERROR;
    }

    // Validate state interface 3 config

    if (joint.state_interfaces[2].name != hardware_interface::HW_IF_EFFORT) {
      RCLCPP_FATAL(
        rclcpp::get_logger("TwigHardware"),
        "Joint '%s' have %s state interface. '%s' expected.", joint.name.c_str(),
        joint.state_interfaces[2].name.c_str(), hardware_interface::HW_IF_EFFORT);
      return hardware_interface::CallbackReturn::ERROR;
    }
  }

  
  // Configure the pull and push rates
  // https://control.ros.org/master/doc/ros2_control/hardware_interface/doc/different_update_rates_userdoc.html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
  pull_rate_ = stod(info_.hardware_parameters["pull_rate"]);
  push_rate_ = stod(info_.hardware_parameters["push_rate"]);


  return hardware_interface::CallbackReturn::SUCCESS;
}

hardware_interface::CallbackReturn TwigHardware::on_configure(
  const rclcpp_lifecycle::State & /*previous_state*/)
{
  for (uint i = 0; i < hw_states_.size(); i++) {
    hw_states_[i] = 0;
  }

  for (uint i = 0; i < hw_commands_.size(); i++) {
    hw_commands_[i] = 0;
  }

  // Docs for hardware params:
  // https://control.ros.org/master/doc/ros2_control/hardware_interface/doc/different_update_rates_userdoc.html
  
  // Load all twig driver hardware configurations from hardware params
  TwigHardwareConfig c;
  c.connectionTimeout = stoi(info_.hardware_parameters["hardware_config.connection_timeout"]);
  
  c.maxShoulderCurrent = twig.current_to_raw_psm(stod(info_.hardware_parameters["hardware_config.max_current"]));
  c.maxWristCurrent = twig.current_to_raw_psm(stod(info_.hardware_parameters["hardware_config.max_current"]));
  c.maxGripperCurrent = twig.current_to_raw_acs(stod(info_.hardware_parameters["hardware_config.max_current"]));
  c.maxCurrentDuration = stoi(info_.hardware_parameters["hardware_config.max_current_duration"]);
  c.maxCurrentCooldownDuration = stoi(info_.hardware_parameters["hardware_config.max_current_cooldown_duration"]);
  c.encoderMinMagnitude = stoi(info_.hardware_parameters["hardware_config.encoder_min_magnitude"]);
  twig.set_hardware_config(c);

  // Load all twig driver joint configurations from hardware params
  twig.jointConfig.shoulderLimits.min = stod(info_.hardware_parameters["joint_config.shoulder.limits.min"]);
  twig.jointConfig.shoulderLimits.max = stod(info_.hardware_parameters["joint_config.shoulder.limits.max"]);

  twig.jointConfig.gripperLimits.min = stod(info_.hardware_parameters["joint_config.gripper.limits.min"]);
  twig.jointConfig.gripperLimits.max = stod(info_.hardware_parameters["joint_config.gripper.limits.max"]);

  twig.jointConfig.shoulderOffset = stod(info_.hardware_parameters["joint_config.shoulder.offset"]);
  twig.jointConfig.wristOffset = stod(info_.hardware_parameters["joint_config.wrist.offset"]);
  twig.jointConfig.gripperOffset = stod(info_.hardware_parameters["joint_config.gripper.offset"]);

  // Push the configurations to hardware
  if (twig.write_command()) {
    RCLCPP_INFO(rclcpp::get_logger("TwigHardware"), "Successfully configured!");
    return hardware_interface::CallbackReturn::SUCCESS;
  }

  RCLCPP_ERROR(rclcpp::get_logger("TwigHardware"), "Failed to configure hardware!");
  return hardware_interface::CallbackReturn::ERROR;
}
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

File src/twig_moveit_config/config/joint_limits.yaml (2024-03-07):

# joint_limits.yaml allows the dynamics properties specified in the URDF to be overwritten or augmented as needed

# For beginners, we downscale velocity and acceleration limits.
# You can always specify higher scaling factors (<= 1.0) in your motion requests.  # Increase the values below to 1.0 to always move at maximum speed.
default_velocity_scaling_factor: 0.1
default_acceleration_scaling_factor: 0.1

# Specific joint properties can be changed with the keys [max_position, min_position, max_velocity, max_acceleration]
# Joint limits can be turned off with [has_velocity_limits, has_acceleration_limits]
joint_limits:
  twig_left_finger_joint:
    has_velocity_limits: true
    max_velocity: 1.0
    has_acceleration_limits: false
    max_acceleration: 0.0
  twig_right_finger_joint:
    has_velocity_limits: true
    max_velocity: 1.0
    has_acceleration_limits: false
    max_acceleration: 0.0
  twig_shoulder_joint:
    has_velocity_limits: true
    max_velocity: 5.0
    has_acceleration_limits: false
    max_acceleration: 0.0
  twig_wrist_joint:
    has_velocity_limits: true
    max_velocity: 5.0
    has_acceleration_limits: false
    max_acceleration: 0.0

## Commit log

2024-01-26 Line endings
    [main.sdf]
2024-02-07 Adds urdf for manipulator
    [manipulator.urdf, manipulator.urdf.xacro]
2024-02-08 Adds panda_movit_config from moveit2 demo
    [joint_limits.yaml, panda.ros2_control.xacro, panda.urdf.xacro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]
2024-02-09 Switches to single ros2 container
2024-02-10 Removes unused gazebo files
    [main.sdf, model.sdf]
2024-02-16 Adds vscode task buttons
2024-02-27 Adds more task buttons
2024-03-01 Half-functioning teleopt
    [controller_mappings.yaml]
2024-03-07 Adds twig_description package
    [twig.urdf.xacro]
2024-03-07 Adds twig_moveit_config from MoveitSetupAssistant
    [joint_limits.yaml, ros2_controllers.yaml, twig.ros2_control.xacro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]
2024-03-07 Updates auv_manipulator urdf file
    [manipulator.urdf.xacro]
2024-03-07 Updates twig gripper velocity limits
    [joint_limits.yaml, manipulator.urdf.xacro, twig.urdf.xacro]
2024-03-07 Reverses direction or twig shoulder and wrist axis
    [twig.urdf.xacro]
2024-03-07 Removes the hand_controller to make the gripper servoable
    [ros2_controllers.yaml]
2024-03-07 Adds copy of twig_teleop renamed as panda_teleop
    [controller_mappings.yaml]
2024-03-08 Removes unused packages
    [controller_mappings.yaml, joint_limits.yaml, manipulator.urdf.xacro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]
2024-03-09 Fixes twig_teleop crashing due to empty joy message
    [joystick_teleop.config.yaml, joystick_teleop.cpp]
2024-03-14 Updates firmware i2c address
2024-03-14 Adds servo relay code to firmware
2024-03-14 Increases size of current and voltage sensor variables
2024-03-24 Adds twig_hardware
    [twig_hardware.ros2_control.xacro]
2024-03-24 Adds arduino.json config
2024-03-24 Fixes incorrect datatype for firmware baudrate
    [firmware.ino]
2024-03-24 Fixes invalid implementation syntax
    [twig_lib.cpp]
2024-03-24 Adds temporary velocity commands
2024-03-24 Changes firmware to send correct stop signal to servos
    [firmware.ino, twig_lib.cpp]
2024-03-24 Moves velocity calculation to firmware
2024-03-24 Fixes typos in direct teleop node
    [joystick_direct_teleop.cpp]
2024-03-24 Adds astop message after arm button gets released
2024-03-24 Add custom velocity tracking to firmware
2024-03-24 Use state class for i2c receive size
2024-03-24 Adds watchdog timer to firmware
2024-03-28 Removes periodic velocity computation
2024-04-20 Inverts servo relay logic
    [firmware.ino]
2024-04-20 Adds encoder magnitude publishers
2024-04-20 Simplifies teleop button configs
2024-05-04 Fixes typo in joystick_teleop
    [joystick_teleop.cpp]
2024-05-15 Adds joint limits and offsets
2024-05-15 Adds sesstions to detect hardware and driver reboots
    [TwigState.h, firmware.ino, joystick_direct_teleop.cpp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]
2024-05-15 Adds fuse
2024-05-15 Adds current unit conversion for max current params
2024-05-15 Adds driver reboot push check
    [twig_hardware_node.cpp, twig_lib.cpp]
2024-05-15 Adds improved driver sync logic
2024-05-15 Removes unused timer
2024-05-15 Adds separate encoder thread
2024-05-15 Adds separate main thread
2024-05-15 Gives main thread higher priority
2024-05-15 Adds improved lowpass filter to firmware
2024-05-15 Makes the thread run methods public for easy debugging
2024-05-15 Updates Thread.h to use static task function
2024-05-15 Moves softi2c and encoders to local context to save memory
2024-05-15 Creates temporary fix for threading issue
    [firmware.ino]
2024-05-15 Stops the connection timer completely during session missmatch
2024-05-15 Adds close_connection call during i2c open in twig_lib
2024-05-15 Switches sda input pins for shoulder and wrist encoders
2024-05-15 Adds Raspberry Pi Pico firmware upload docs
2024-05-15 Updates the firmware to work on pico
2024-05-15 Updates encoder thread priority
2024-05-15 Increases default Thread stack size to 256
2024-05-15 Returns SoftI2C and encoder instances to global context
2024-05-15 Updates pinouts in firmware to reflect pico installation
2024-05-15 Adds encoder magniude logging
2024-05-15 Adds i2c pin assignment in firmware
2024-05-15 Fixes incorrect TwigState in driver
    [twig_lib.hpp]
2024-05-15 Revert "Adds checksums"
    This reverts commit 05c17ddd11c9587718494a581e57b67c61f16cd8.
    [TwigState.h, firmware.ino, twig_hardware_node.cpp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]
2024-05-15 Adds iintegrity check for pi to pico i2c bus
2024-05-15 Inverts positioon limit logic
    [twig_lib.cpp]
2024-05-15 Adds correct offsets for shoulder and wrist
    [node.config.yaml]
2024-05-15 Disables gripper limits
2024-05-15 Lowers min encoder magnitude
2024-05-15 Fixs FusedServo typo
2024-05-15 Fixes incorrect datatypes in ServoFuse
    [FusedServo.h]
2024-05-15 Switches relay on and off buttons in direct_teleop
2024-05-15 Switches griper and wrist joystick keybind
2024-05-15 Updates velocity to servo speed conversion in twig_lib
2024-05-15 Swaps servo and encoder pins in firmware
    [FirmwareConfig.h]
2024-05-15 Updates relay pinouts in firmware
2024-05-15 Add firmware for testing servos
2024-05-15 Updates firmware pins to avoid spi pins for servos
    [FirmwareConfig.h]
2024-05-15 Revert "Add firmware for testing servos"
    This reverts commit 1a335960a47f4d9b9fb89ff73b0062f6241a0629.
    [firmware.ino]
2024-05-15 Adds print to serial during connection timeouts in firmware
2024-05-15 Updates encoder pinouts in firmware
2024-05-15 Disables encoders in firmware to prevent conflict with servo controls
    [firmware.ino]
2024-05-15 Fixes bug where encoders ran on separate thread
    [firmware.ino]
2024-05-15 Adds velocity filter design notebook and logs
2024-05-15 Removes voltage sensors and topics from code
2024-05-15 Adds automatic hardware and driver reboot acknowledgement in TwigHardwareInterface
    [twig_hardware.cpp]
2024-05-15 Adds hardware and joint config to TwigHardwareInterface
    [twig_hardware.ros2_control.xacro]
2024-05-20 Adds ros2_controllers config for real hardware with PID regulators
    [ros2_controllers.yaml]
2024-05-20 Adds current estimation
2024-05-20 Adds all twig 3d model files
    [twig_arm_47mm_bearing.SLDPRT, twig_arm_assembly.SLDASM, twig_arm_center_shaft.SLDPRT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]
2024-06-02 Makes filter cutoff float
2024-06-02 Moves encoders to i2c multiplexer
2024-06-02 Moves encoder update to separate core
